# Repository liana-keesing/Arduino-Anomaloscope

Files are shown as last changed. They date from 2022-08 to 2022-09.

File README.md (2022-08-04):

# ArduinoAnomaloscope

## Materials

## Assembly Steps

1. Using the [instructions](/Electronics/README.md) in the Electronics folder, assemble the electronics necessary for the anomaloscope. This will require the correct parts (Arduino, shield, components) and soldering.
2. Using the [instructions](/CAD/README.md) and files in the CAD folder, 3D print the required components and assemble the entire anomaloscope.
3. Using the [sample code](/Code/) available in the Code folder and MATLAB, begin experimenting with the anomaloscope!

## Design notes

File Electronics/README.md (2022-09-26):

# Instructions for Electronics

## Supplies
### Materials:
- Arduino Leonardo
- Arduino Prototyping Shield
- 10 mm RGB LED
- 10 mm yellow LED
- 330 Ω resistor
- 270 Ω resistor
- 150 Ω resistor
- two 100 Ω resistors
- Heat shrink
- Solid core 22 or 24 gauge wire in black, red, and 3 other assorted colors

### Tools
- Soldering iron + accessories (solder, tip cleaning wire sponge, etc)
- Clip of some sort to hold electronics in place while soldering
- Wire strippers
- Wire snippers
- Heat gun for the heat shrink

## Instructions

Beginning by prepping the wire that you will need. You will need:
- Two 4-inch pieces of black wire
- One 4-inch piece of each red and three other colors
In total, you should have 6 pieces of cut wire.

If you're unfamiliar with the process of soldering, take a second to review [these instructions](https://lab64.stanford.edu/basic-soldering), courtesy of Stanford's lab64 makerspace.

First, we will prep the prototyping shield. Note that the diagram of the arduino shield shown in the schematic is for an Uno shield; we are using the Leonardo.  From reading on the web, it appears that the shields are basically compatible but that some Uno shields don't physically fit the Leonardo.  The shield in the PartsList.xlxs file does work with our Leonardos. It has labels that match up with those in the UNO diagram, but the physical locations aren't the same as the diagram shown in the instructions.  The two images ShieldFront.jpg and ShieldBack.jpg show pictures of the assembled shield we are using.

Snip the male-to-male headers into four pieces to match the width of the four block of female headers on the Arduino Leonardo. Then, solder the headers into the prototyping shield such that it matches the Leonardo and can be used as a shield for the Leonardo. If you are struggling to ensure they line up perfectly, stick the male-to-male headers into the Leonardo's female headers, and wiggle the prototyping shield so that the holes align with the male headers that are sticking up. Then, mark those spots, take the setup apart, and proceed to solder the male-to-male headers into the marked locations.

Once the prototyping shield is prepped, we can move to the LEDs. 

Begin with the yellow LED. Note that the positive leg of the LED is longer.  Solder a red wire to the positive leg and a black wire to a 330 Ω resistor to the negative leg, as shown below. Once finished, make sure to push heatshrink over each of the exposed wires/resistor, up to the bottom of the LED, and use the heat gun to attach it. See the picture below for more detail.

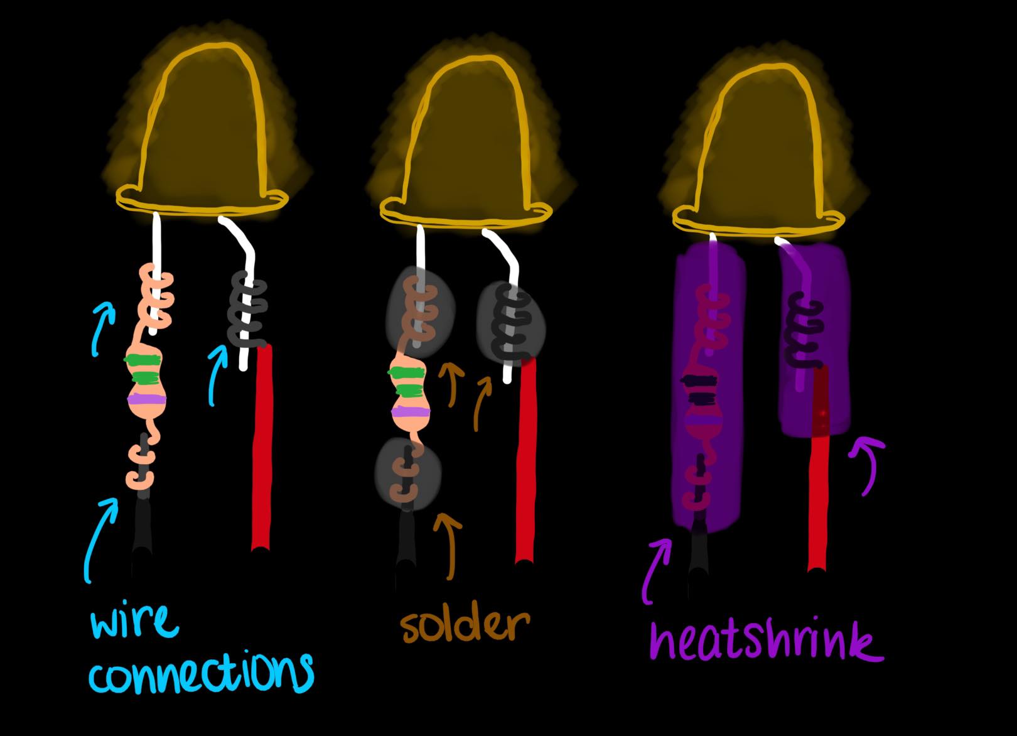
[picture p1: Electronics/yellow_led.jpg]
Yellow LED


Next, do the same with the RGB LED. Use the 150 Ω resistor for the red leg of the LED and a 100 Ω for each of the green and blue legs. Solder those resistors to three wires of different colors. Attach the black wire to the negative leg. Just like before, use heatshrink over the open connections. Use the picture below as a reference.

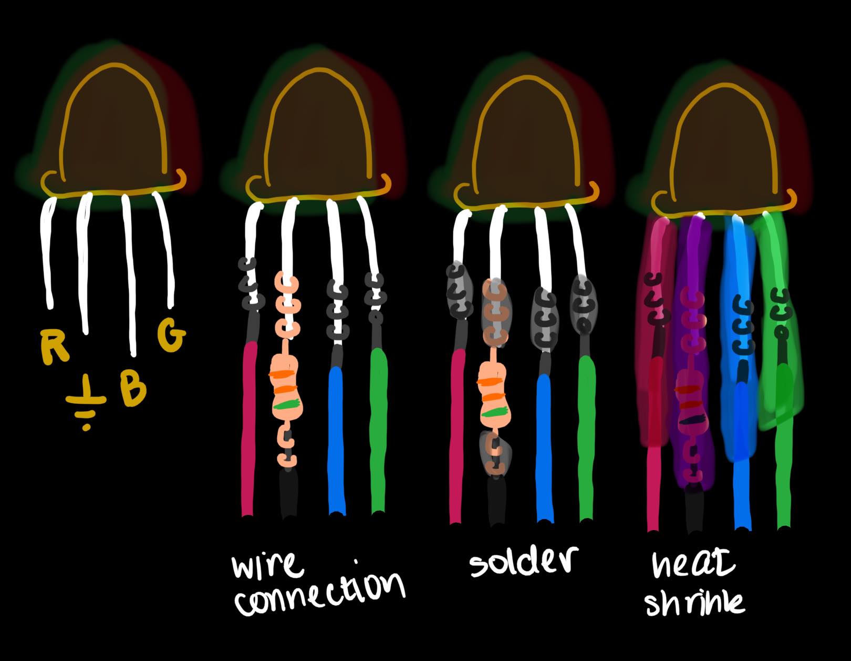
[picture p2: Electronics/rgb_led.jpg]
RGB LED


Finally, you need to solder the LEDs to the Arduino shield. How this happens will depend on the specifics of the Arduino shield you use, but the following must be true:

For the RGB LED, the red leg must connect to D6, the green leg to D5, and the blue leg to D3. The negative leg needs to connect to ground. For the yellow LED, the positive leg must connect to D9, and the negative leg needs to connect to ground. See this schematic for specifics.

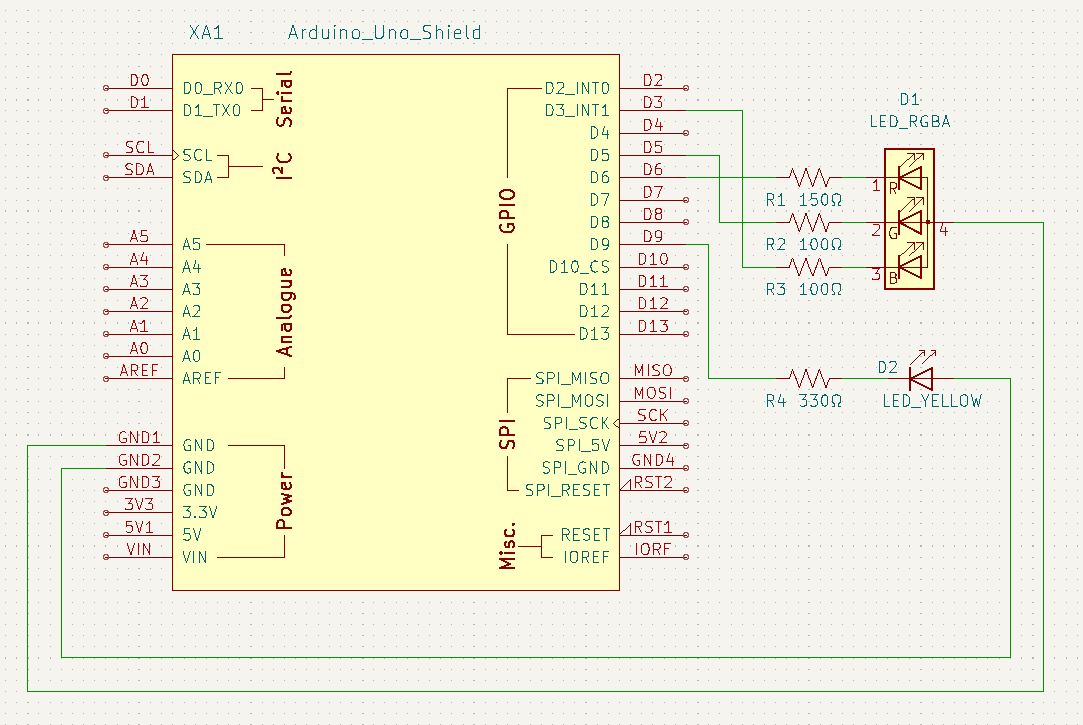
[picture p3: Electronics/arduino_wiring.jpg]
Arduino Wiring


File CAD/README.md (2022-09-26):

# Instructions for CAD & Assembly

### Materials:
- 3D printer
- white filament (I used PLA, but any material that is stiff and has good geometric stability should be fine!)
- 400-4000 grit sandpaper (optional)
- two square inches of [Rosco #23 orange-colored filter](https://www.bhphotovideo.com/c/product/43934-REG/Rosco_RS2311_23_Filter_Orange.html)
- completed & assembled electronics (Arduino + shield + components)
- a rubber band or hairband to hold the enclosure together

### Instructions

Using the splicer of your choice, download the STL files and assemble them onto the print bed, selecting your desired print settings. Note that you will need to print:
- 1 **Base**
- 1 **MidLayer**
- 1 **TopLayer**
- 2 **Rod**s

For each of these STL files, you can view a PNG of the design in this folder as well.

If you used PLA filament and have sandpaper available, it can often be nice to smooth the edges of your 3D printed parts, beginning with the coarsest sandpaper and working your way up. However, this step is optional and purely aesthetic.

Using scissors, cut the orange filter paper into two small hexagons so that each hexagon lies flatly on the inside of openings at the top of **TopLayer**. This can be a tricky process, as you want to make the hexagons you cut small enough to lay flatly inside, but not so small that they do not evenly cover the open channel. Begin by cutting two squares that are much bigger than necessary, and then cutting them down, bit by bit, until they reach the correct size.

To put everything together, you will need to place the Arduino and the attached shield inside the **Base**, making sure to line up the USB port with the side of the **Base** with the corresponding opening. The LEDs should be poking up from the top. Then, slide the two LEDs through the opening on **MidLayer**, lining each LED up with its own hole. Push the **MidLayer** down until it fits into the **Base**, and push the LEDs down so that they lie evenly aginst the **MidLayer**. At this point, it should look like a box with two LEDs poking out of the top (it's okay if you need to hold it in place to achieve that effect). If the LEDs are poking up so much that they don't look evenly flat against the **MidLayer**, try to pull the extra wire on their connections underneath the **MidLayer** as much as possible so that they are pulled evenly.

At this point, place the flat side of **TopLayer** on top of **MidLayer**, allowing the holes on the flat part of **TopLayer** to line up with the LEDs. You should be able to see both LEDs evenly through the two rod openings sticking out of **TopLayer**. Use the rubber band to hold the entire enclosure together, wrapping it between the two rod openings on the top of **TopLayer** and down around the notch at the bottom of the **Base** (make sure this is tight enough to hold everything in place--you might need to wrap it around twice to keep it taut).

Finally, place the two hexagon filters that you cut previously into the tops of the rod openings on **TopLayer**, placing care to lay them evenly to cover the openings. Push each **Rod** into those openings (effectively snapping the filter into place). Look through each rod and make sure that the enclosure looks even, the rods look straight, the filter paper completely covers the openings, and the LEDs are even.

[This video](https://onedrive.live.com/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) demonstrates the process as well.

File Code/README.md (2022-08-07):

This code and these programs were developed by the Brainard Lab--the original code is on [Github](https://github.com/BrainardLab/TeachingCode/tree/master/ArduinoAnomaloscope).

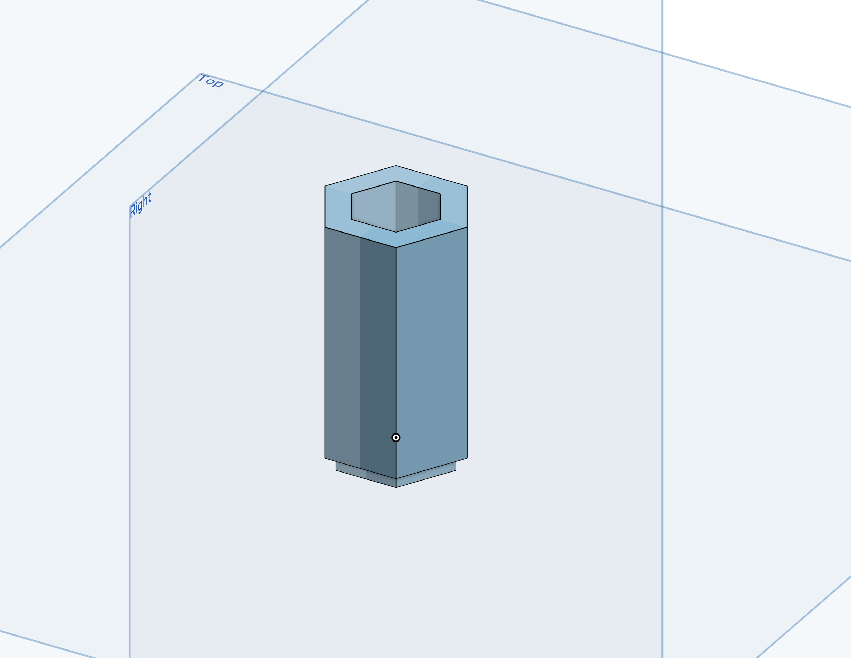
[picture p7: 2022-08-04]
CAD/Rod.png

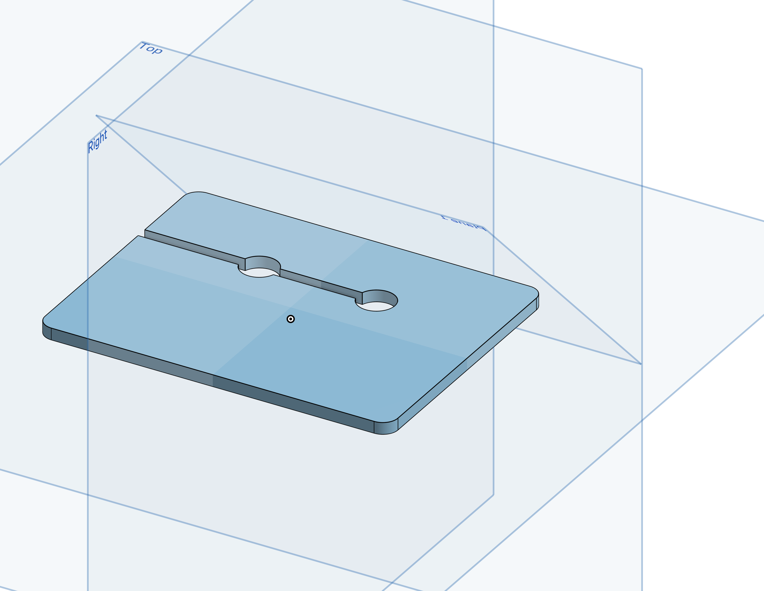
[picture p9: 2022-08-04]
CAD/MidLayer.png

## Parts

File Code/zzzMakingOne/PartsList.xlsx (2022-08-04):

Date | Company | Product | PID | Link | Price per Unit | # of Units | Cost | Order Cost w/ Tax & Shipping
2019-10-30 | Adafruit | Diffused RGB (tri-color) 10mm LED (10 / order) | 848 | https://www.adafruit.com/product/848 | $9.95 | 1 | $9.95 | $71.06
2019-10-30 | Adafruit | Diffused Yellow 10mm LED (25 / order) | 3260 | https://www.adafruit.com/product/3260 | $9.95 | 1 | $9.95
2019-10-30 | Adafruit | Extra-long 0.1" 16-pin strip male header (5 / order) | 400 | https://www.adafruit.com/product/400 | $3.00 | 5 | $15.00
2019-10-30 | Adafruit | Adafruit Proto Shield for Arduino V:R3 | 2077 | https://www.adafruit.com/product/2077 | $9.95 | 2 | $19.90
2020-03-26 | Prusa | Prusament ASA Natural 850g | PRM-ASA-NAT-850 | https://shop.prusa3d.com/en/prusament/976-prusament-asa-natural-850g.html | $29.99 | 1 | $29.99 | $32.09
2020-11-29 | B&H | Rosco Roscolux #23 Filter - Orange - 20x24" Sheet | BH #RO23S | https://www.bhphotovideo.com/c/product/43934-REG/Rosco_RS2311_23_Filter_Orange.html | $6.95 | 3 | $20.85 | $30.89
2021-05-03 | Prusa | Prusament ASA Signal White 850g | PRM-ASA-SGW-850 | https://shop.prusa3d.com/en/prusament/1318-prusament-asa-signal-white-850g.html | $28.49 | 2 | $56.98 | $72.52
2021-04-23 | Adafruit | Diffused RGB (tri-color) 10mm LED (10 / order) | 848 | https://www.adafruit.com/product/848 | $9.95 | 2 | $19.90 | $185.47
2021-04-24 | Adafruit | Extra-long 0.1" 16-pin strip male header (5 / order) | 400 | https://www.adafruit.com/product/400 | $2.70 | 11 | $29.70
2021-04-25 | Adafruit | Adafruit Proto Shield for Arduino V:R3 | 2077 | https://www.adafruit.com/product/2077 | $8.96 | 11 | $98.56
2021-04-26 | Adafruit | Hook-up Wire Spool Set - 22AWG Solid Core | 1311 | https://www.adafruit.com/product/1311 | $15.95 | 1 | $15.95
2021-05-28 | Amazon | Arduino Leonardo with Headers | A000057 | https://www.amazon.com/gp/product/B008FZJC74/ref=ppx_od_dt_b_asin_title_s00?ie=UTF8&psc=1 | $25.15 | 11 | $276.65 | $293.26
 |  |  |  |  |  |  | $603.38 |  | Roughly speaking, this was the cost to make 10

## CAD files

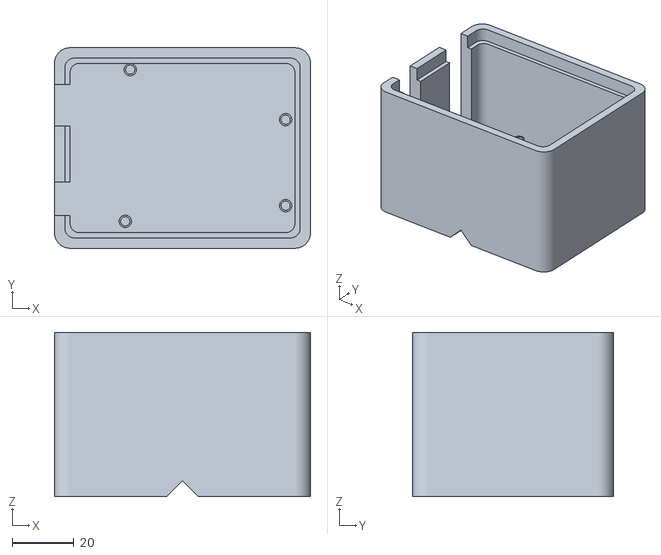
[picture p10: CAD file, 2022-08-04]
CAD/Base.stl
83.2 x 65.2 x 53.3

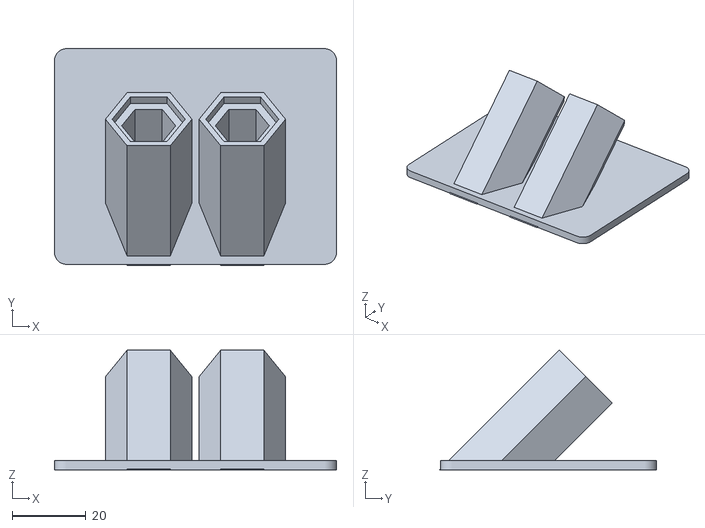
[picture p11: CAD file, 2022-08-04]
CAD/TopLayer.stl
76.5 x 58.8 x 32.4

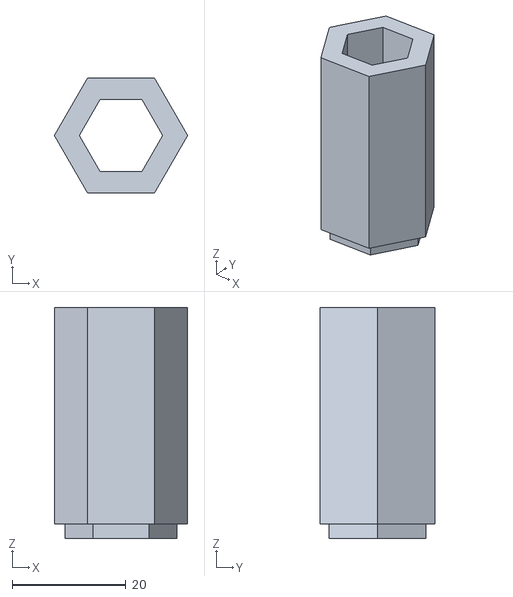
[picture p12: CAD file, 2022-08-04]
CAD/Rod.stl
23.5 x 20.3 x 40.6

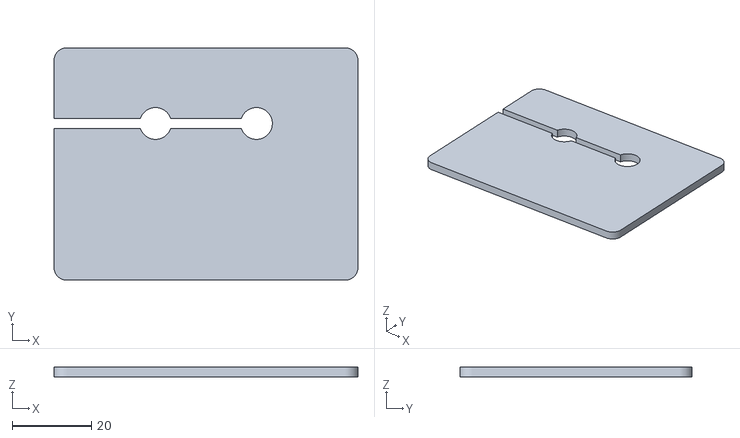
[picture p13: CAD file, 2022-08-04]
CAD/MidLayer.stl
76.5 x 58.5 x 2.54

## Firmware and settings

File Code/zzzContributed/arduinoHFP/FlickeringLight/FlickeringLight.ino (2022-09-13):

#include <Wire.h>
#include <stdio.h>
#include <stdlib.h>
#include <Keyboard.h>

//before starting remember to check that tools/port shows the port with the arduino hardware

// define twopi (2*pi) and the frequency
const double TWOPI=6.2831853;
const int Freq = 25;                               //FREQUENCY

// define red and green output pins (red=D6, green=D5)
const int rOutPin=6;
const int gOutPin=5;

// define all variables (amplitude of red ang green, red minimum, maximum, and start value (0-255) 
// green value (0-255) red phase setting (degrees), red phase (radiants), red and green wave value, 
// time. 
double gAmp;
double rAmp;
int rValMax=255;
int rValMin=0;
double rVal=round(random(rValMax*.4, rValMax*.6));  //RED VAL
double rValinit = rVal;                         
double gVal=255;                                    //GREEN VAL
int rPhaseSetting=180;
double rPhase=rPhaseSetting/360.0*TWOPI;;
double gWave;
double rWave;
unsigned long time;

// define the input signal from matlab. q,w,e will cause a 20, 5, 1 bytes increase and r,t,y will 
// cause a 20, 5, 1 bytes decrease in the red intensity. 
int InputFromMatlab;

void setup() {
  // Start communication with computer (baud rate 9600, has to be the same as the receiving program/
  // serial monitor)
  Serial.begin(9600);
  
  // set red ang green pins as output pins
  pinMode(rOutPin, OUTPUT);
  pinMode(gOutPin, OUTPUT);

  // calculate starting red and green amplitudes (0-1). 
  rAmp=(double)rVal/255.0;
  gAmp=(double)gVal/255.0;

  // find current time
  time=micros();  

  // calculate current output value based on current time (as the loop repeats, the values will follow
  // a sinewave). rPhase allows red to peak when green is lowest and viceversa. the "/2+.5" part is 
  // necessary to put the [-1 1]-ranged sinewave into range [0 1].
  rWave=(sin(TWOPI*(float)Freq*(float)time/1000000+rPhase)/2.0+0.5)*rAmp;
  gWave=(sin(TWOPI*(float)Freq*(float)time/1000000)/2.0+0.5)*gAmp;

}

void loop() {
  // Send values to arduino hardware. LEONARDO (or Leo if you prefer) requires 0-255 input, where
  // 0 is the maximum intensity and 255 is the minimum. This inversion here allows us to work with 
  // 255 as max and 0 as min in all the rest of the code.
  analogWrite(rOutPin,255-(rWave*255));
  analogWrite(gOutPin, 255-(gWave*255));
  
  // find new amplitudes
  rAmp=(double)rVal/255;
  gAmp=(double)gVal/255;

  // find new time to move along the sinewave
  time=micros();  

  // find output values at this time. See above for explanation
  rWave=(sin(TWOPI*(float)Freq*(float)time/1000000+rPhase)/2.0+0.5)*rAmp;
  gWave=(sin(TWOPI*(float)Freq*(float)time/1000000)/2.0+0.5)*gAmp;

 
  
  
  // HERE STARTS THE PART OF CODE WHERE THE INPUT FROM MATLAB CHANGES THE INTENSITY OF THE RED LED
  if (Serial.available()){
  InputFromMatlab=Serial.read();
  if (InputFromMatlab=='q'){
    rVal=rVal+20;
    if (rVal>rValMax){
      rVal=rValMax;
    }
  }
  if (InputFromMatlab=='w'){
    rVal=rVal+5;
    if (rVal>rValMax){
      rVal=rValMax;
    }
  }
  if (InputFromMatlab=='e'){
    rVal=rVal+1;
    if (rVal>rValMax){
      rVal=rValMax;
    }
  }    
  if (InputFromMatlab=='r'){
    rVal=rVal-20;
    if(rVal<rValMin){
      rVal=rValMin;
    }
  }
  if (InputFromMatlab=='t'){
    rVal=rVal-5;
    if(rVal<rValMin){
      rVal=rValMin;
    }
  }
  if (InputFromMatlab=='y'){
    rVal=rVal-1;
    if(rVal<rValMin){
      rVal=rValMin;
    }
  }
  if (InputFromMatlab=='f'){
    // Send initial and final red intensity to MATLAB
    Serial.print(rValinit);
    Serial.print(rVal);

  }
  if (InputFromMatlab=='s'){
    // set random initial red intensity (between .4 and .6 quantiles) for new trial. And save
    // new initial settings
    rVal=round(random(rValMax*.4, rValMax*.6));
    rValinit=rVal;
    Serial.print(rVal);
    Serial.print(gVal);
  }
  InputFromMatlab=0;
}
}
